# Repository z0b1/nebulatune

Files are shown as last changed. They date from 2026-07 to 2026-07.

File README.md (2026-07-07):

# NebulaTune

NebulaTune is a HF reciever utilizng a Direct Conversion Single Balanced Diode Product Detector along with an RP2350 to display and choose frequency and recieve with an digital encoder!

## Preview

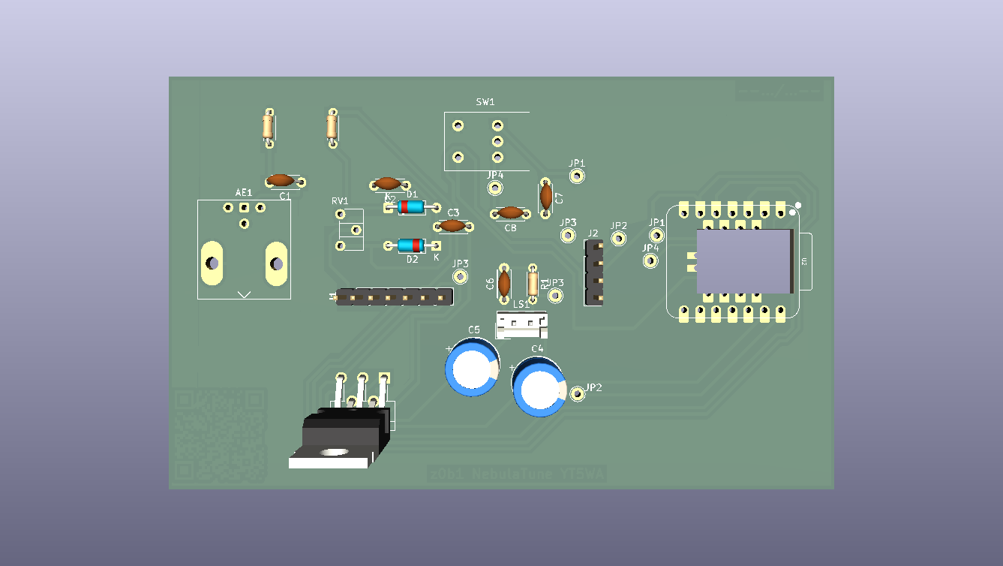
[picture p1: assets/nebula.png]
PCB preview

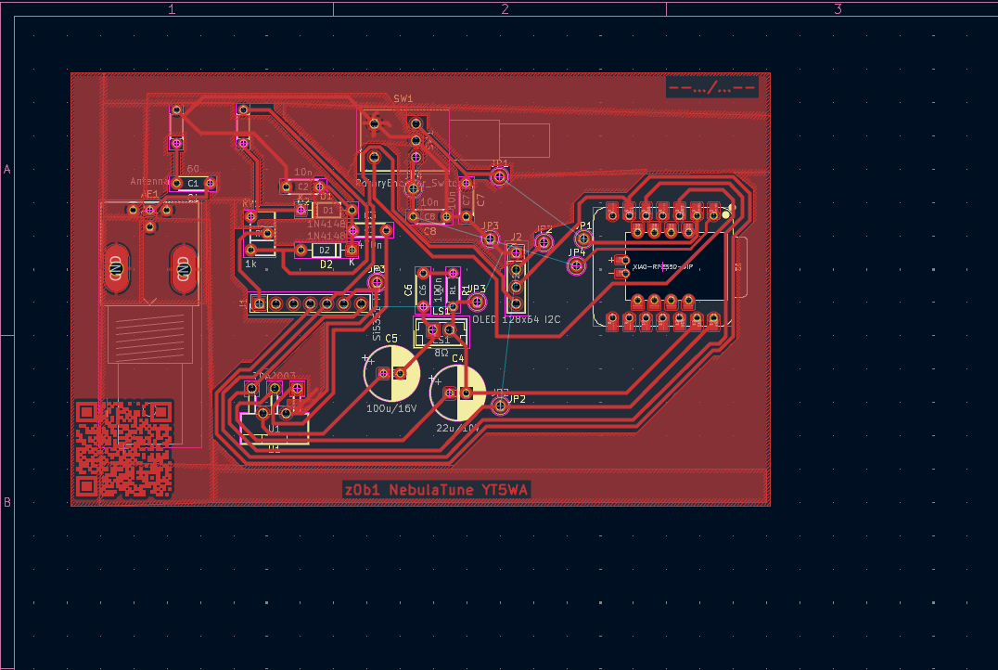
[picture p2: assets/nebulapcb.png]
Routing preview

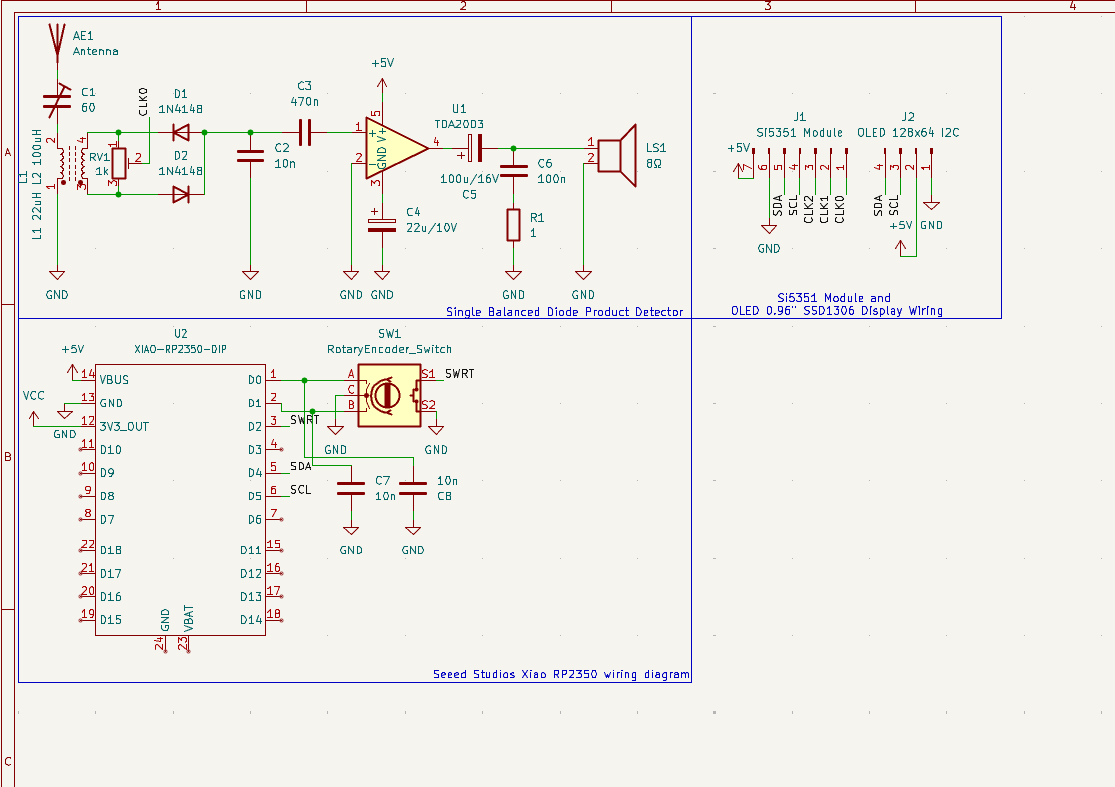
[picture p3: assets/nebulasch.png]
Schematic preview

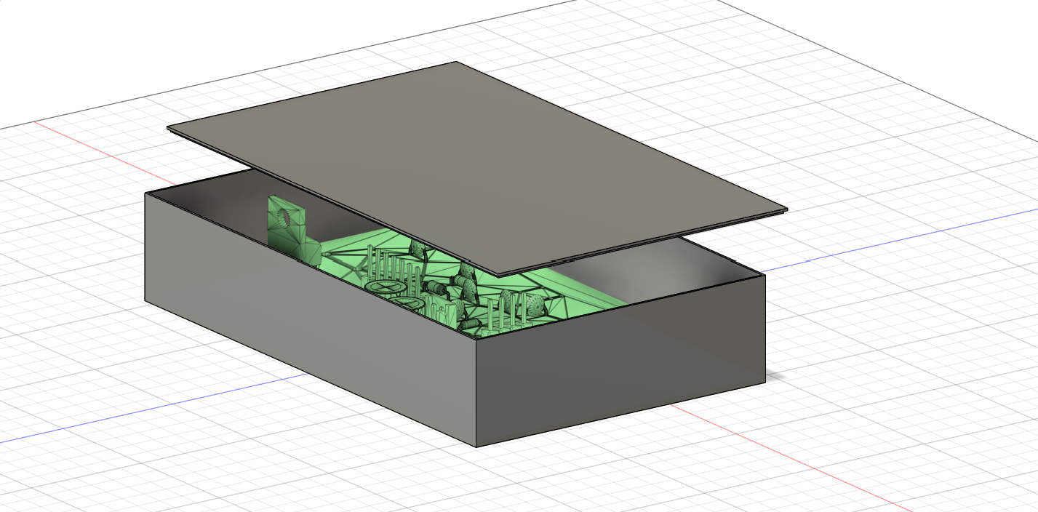
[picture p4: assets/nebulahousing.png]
Housing preview

---
# Lapse link
[View Timelapses](https://lapse.hackclub.com/timelapse/dcauUObcYn6o/)
---
# Demo

##  - link to the PCB on KiCanvas
## SCH in KiCanvas (https://kicanvas.org/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) - link to the SCH on KiCanvas

# Features

- Adjustable VFO with a rotary encoder;
- Frequency display;
- Direct Conversion Single Balanced Diode Product Detector;
- Speaker or headphones output;
- Wide range of frequencies(3-30MHz);
- Local oscillator high stability crystal Si5351 by SiliconLabs;
- SDR and waterfall display soon&trade;.

# DIY How to

1. Analyze the schematic and PCB design and determine if these fit your needs;

2. Gather all of the needed parts from the BOM;

3. A housing is wished for but not needed especially if you plan on tweaking my design;

4. Print the PCB(Only the `F.Cu` and that is in reverse) or order it from JLCPCB(not sponsored);

5. Install the MicroPico extension if using VS Code or just use Thonny;

6. More to come later...

# How it works
 
## General overview

This direct conversion single balanced diode product detector setup is pretty common, it utilizes the Si5351 as the local VFO. That way we eliminate the need for a frequency counter, because the frequency can be set and read with the RP2350!

## Tech details
Now lets get to the core, this direct conversion single balanced diode product detector is similar to Polyakov's mixer which is a small and easy to setup/begginer friendly HF reciever. I took inspo for the 7MHz band design, but with some tweaking the reciever should work on the whole HF band. I choose to make a reciever becuase you don't need a license to listen, and hope to bring more people into Ham Radio. The reason I used the RP2350 is because I hope to make a waterfall and split this into I and Q signals, so I can do ADC on the RP2350 and hopefully make an HF SDR Transciever.

## Explanation

Now, I hope that the reader know what HF and SDR mean, but just in case if someone doesn't know, I will explain the meaning of HF and SDR to you, also some other technical terms I used in this README.
HF just means High Frequency and that is the defined range of frequencies **in this case (3MHz to 30MHz)**. There are also other ranges like VHF, UHF, EHF, SHF and so on!
SDR means Software Defined Radio, that is if your microcontroller/PC analyze the input values of your ADC(Analog to Digital Converter) and visualise it and control the Radio via the Software.

## I'd like to add

I'd like to add although I'm in this hobby for 8 years already, and despite me being a hardware fanatic this is only my second RF project so please contribute and tell me if I have made any mistakes! Also I'm currentley looking for sponsors for my YSWS called **Propagation**!
### Propagation

Propagation is a Hack Club YSWS in production, the idea behind this is that many people have never heard of or tried the magics of RF, our goal is to get people to make projects relating RF, learn about RF and maybe get into the hobby. What separates us from other Radio related YSWS's is that we do not require a license, would be incredible if you have one but our main goal is to expand the use of RF in every sphere of life!
# Credits
Big shoutout to my father, without him, having patience and will to work is getting hard as I easily get annoyed but he gets me to enjoy this, also he's the main finder of other open source projects which I later work on and modify
---
### The idea for using the Si5351
---
[Link to github repository of the inspo for the Si5351.](https://github.com/TeknoTrek/Si5351-Clock-Generator-for-Arduino-Projects)
---
### The idea for the Direct Conversion Single Balanced Diode Product Detector
---
[Link to the Direct Conversion Single Balanced Diode Product Detector.](https://ra1ohx.ru/publ/skhemy_radioljubitelju/priemniki/prostoj_priemnik_prjamogo_preobrazovanija_na_diapazon_7_mgc/13-1-0-153)
---
> Translate the site to english, its in russian.
# Bill Of Materials
---
|Reference|Part|Qty|Price|Total|Description|
|:---|:---:|:---|:---:|:---:|:---:|
|AE1|Antenna|1|3.66E|3.66E|BNC CONNECTOR|
|C1|Capacitor|1|0.3E|0.3E|60|
|C2,C7,C8|Capacitor|3|0.1E|0.3E|10n|
|C3|Capacitor|1|0.15|0.15|470n|
|C4|CP|1|0.2|0.2|22u/10V|
|C5|CP|1|X|X|100u/16V|
|C6|Capacitor|1|X|X|100n|
|D1,D2|Diode|2|X|X|1N4148|
|J1|VFO|1|6.5|6.5|Si5351|
|J2|Display|1|6.8|6.8|OLED 128x64 I2C|
|L1|Inductor/Choke Coupled|1|0.2|0.2|L1 22uH L2 100uH|
|LS1|Speaker|1|2.8|2.8|8Ohm|
|R1|Resistor|1|x|x|1|
|RV1|Trimmer|1|0.2|0.2|1k|
|SW1|Rotary encoder swithch|1|1|1|/|
|U1|TDA2003|1|1.5|1.5|Audio amp|
|U2|XIAO RP2350 DIP|1|9|9|Main MCU|
> Total 32.61 Euros or 37.33 USD, price might vary for shipping and availabilty reasons.

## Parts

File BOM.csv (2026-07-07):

Reference | Qty | Value | DNP | Exclude from BOM | Exclude from Board | Footprint | Datasheet
AE1 | 1 | Antenna |  |  |  | Connector_Coaxial:BNC_Amphenol_031-6575_Horizontal
C1 | 1 | 60 |  |  |  | Capacitor_THT:C_Disc_D4.3mm_W1.9mm_P5.00mm
C2,C7,C8 | 3 | 10n |  |  |  | Capacitor_THT:C_Disc_D4.3mm_W1.9mm_P5.00mm
C3 | 1 | 470n |  |  |  | Capacitor_THT:C_Disc_D4.3mm_W1.9mm_P5.00mm
C4 | 1 | 22u/10V |  |  |  | Capacitor_THT:CP_Radial_D8.0mm_P2.50mm
C5 | 1 | 100u/16V |  |  |  | Capacitor_THT:CP_Radial_D8.0mm_P2.50mm
C6 | 1 | 100n |  |  |  | Capacitor_THT:C_Disc_D4.3mm_W1.9mm_P5.00mm
D1,D2 | 2 | 1N4148 |  |  |  | Diode_THT:D_DO-35_SOD27_P7.62mm_Horizontal | https://assets.nexperia.com/documents/data-sheet/1N4148_1N4448.pdf
J1 | 1 | Si5351 Module |  |  |  | Connector_PinHeader_2.54mm:PinHeader_1x07_P2.54mm_Vertical
J2 | 1 | OLED 128x64 I2C |  |  |  | Connector_PinHeader_2.54mm:PinHeader_1x04_P2.54mm_Vertical
L1 | 1 | L1 22uH L2 100uH |  |  |  | Inductor_THT:L_CommonMode_Wuerth_WE-CMB-L
LS1 | 1 | 8Ω |  |  |  | Connector_JST:JST_EH_B2B-EH-A_1x02_P2.50mm_Vertical
R1 | 1 | 1 |  |  |  | Resistor_THT:R_Axial_DIN0204_L3.6mm_D1.6mm_P5.08mm_Horizontal
RV1 | 1 | 1k |  |  |  | Potentiometer_THT:Potentiometer_ACP_CA6-H2,5_Horizontal
SW1 | 1 | RotaryEncoder_Switch |  |  |  | Rotary_Encoder:RotaryEncoder_Bourns_Horizontal_PEC09-2xxxF-Sxxxx
U1 | 1 | TDA2003 |  |  |  | Package_TO_SOT_THT:TO-220-5_P3.4x3.7mm_StaggerOdd_Lead3.8mm_Vertical | http://www.st.com/resource/en/datasheet/cd00000123.pdf
U2 | 1 | XIAO-RP2350-DIP |  |  |  | Seeed Studio XIAO Series Library:XIAO-RP2350-DIP

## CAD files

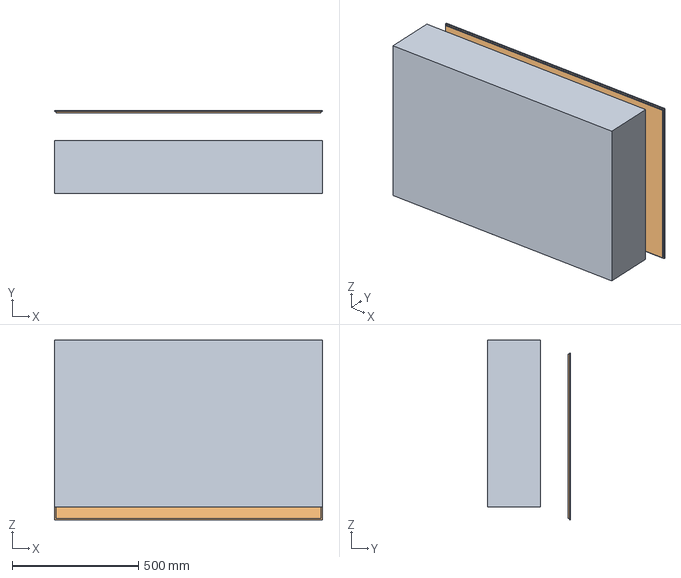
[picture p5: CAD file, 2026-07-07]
CAD/nebulatune_case.step
1060.0 x 330.0 x 710.0 mm

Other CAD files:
CAD/nebulatune_case.stl

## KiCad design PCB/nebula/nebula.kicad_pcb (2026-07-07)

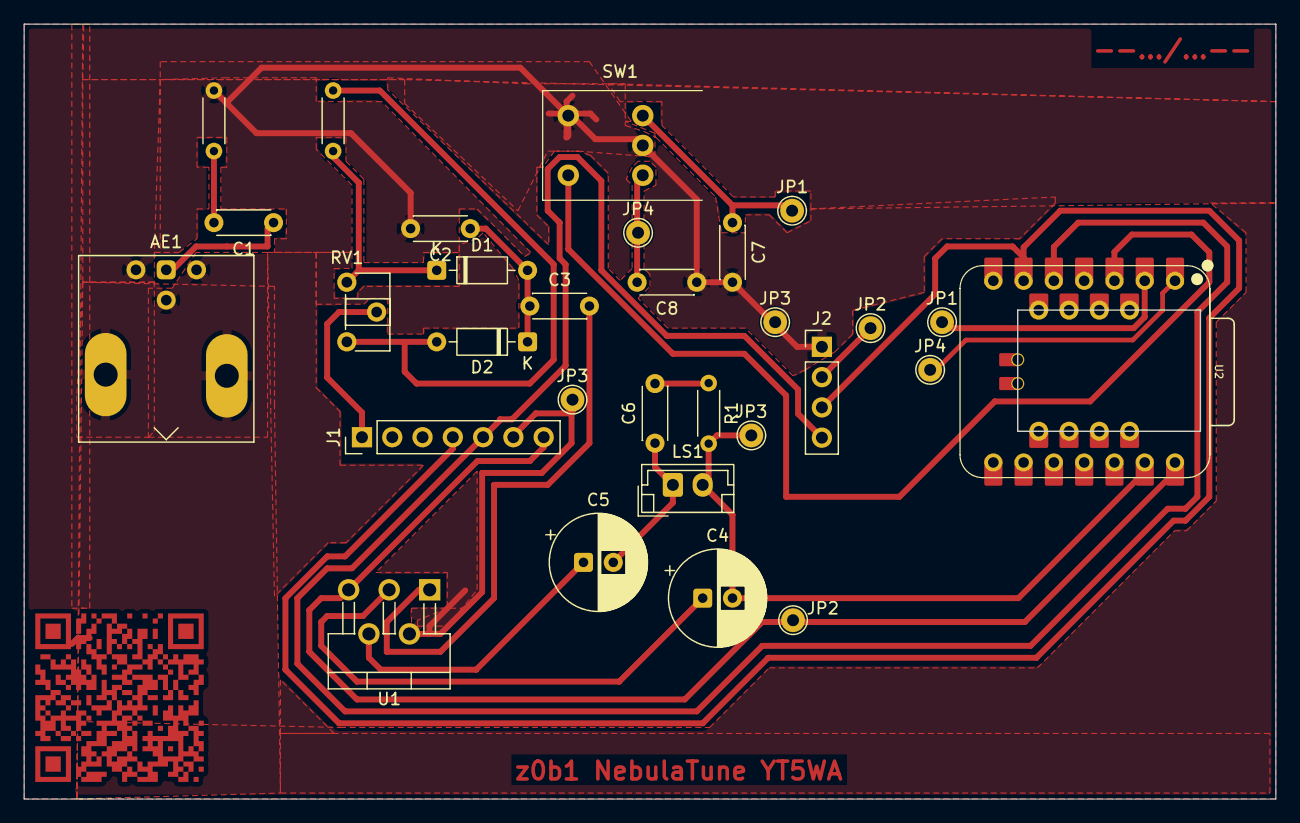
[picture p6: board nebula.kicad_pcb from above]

Board: 2 copper layers, 105.0 x 65.0 mm, 28 parts (0 on the bottom side), 17 nets.

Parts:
AE1: Antenna; BNC_Amphenol_031-6575_Horizontal
C1: 60; C_Disc_D4.3mm_W1.9mm_P5.00mm
C2, C7, C8: 10n; C_Disc_D4.3mm_W1.9mm_P5.00mm
C3: 470n; C_Disc_D4.3mm_W1.9mm_P5.00mm
C4: 22u/10V; CP_Radial_D8.0mm_P2.50mm
C5: 100u/16V; CP_Radial_D8.0mm_P2.50mm
C6: 100n; C_Disc_D4.3mm_W1.9mm_P5.00mm
D1, D2: 1N4148; D_DO-35_SOD27_P7.62mm_Horizontal
J1: Si5351 Module; PinHeader_1x07_P2.54mm_Vertical
J2: OLED 128x64 I2C; PinHeader_1x04_P2.54mm_Vertical
JP1, JP1#2, JP2, JP2#2, JP3, JP3#2, JP3#3, JP4, JP4#2: TestPoint_THTPad_D2.0mm_Drill1.0mm
LS1: 8Ω; JST_EH_B2B-EH-A_1x02_P2.50mm_Vertical
R1: 1; R_Axial_DIN0204_L3.6mm_D1.6mm_P5.08mm_Horizontal
RV1: 1k; Potentiometer_ACP_CA6-H2,5_Horizontal
SW1: RotaryEncoder_Switch; RotaryEncoder_Bourns_Horizontal_PEC09-2xxxF-Sxxxx
U1: TDA2003; TO-220-5_P3.4x3.7mm_StaggerOdd_Lead3.8mm_Vertical
U2: XIAO-RP2350-DIP

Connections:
+5V: J1.7, J2.2, JP2.1, JP2#2.1, U1.5 (V+), U2.14 (VBUS)
/CLK0: J1.1, RV1.2
/SCL: J1.4, J2.3, U2.6 (D5)
/SDA: J1.5, J2.4, U2.5 (D4)
/SWRT: SW1.S1, U2.3 (D2)
GND: AE1.2, AE1.3, AE1.4, C2.2, C4.2, C7.2, C8.1, J1.6, J2.1, JP3.1, JP3#2.1, JP3#3.1, LS1.2, R1.2, SW1.C, SW1.S2, U1.2 (-), U2.13 (GND)
unnamed: AE1.1 (A_1), C1.1
unnamed: C5.1, U1.4
unnamed: C5.2, C6.1, LS1.1
unnamed: C6.2, R1.1
unnamed: C2.1, C3.1, D1.2 (A), D2.1 (K)
unnamed: D1.1 (K), RV1.1
unnamed: D2.2 (A), RV1.3
unnamed: C3.2, U1.1 (+)
unnamed: C4.1, U1.3 (GND)
unnamed: C8.2, JP4.1, JP4#2.1, SW1.A, U2.1 (D0)
unnamed: C7.1, JP1.1, JP1#2.1, SW1.B, U2.2 (D1)

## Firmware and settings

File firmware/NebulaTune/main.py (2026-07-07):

import machine
import utime
from si5351 import SI5351
from ssd1306 import SSD1306_I2C

i2c = machine.I2C(0, sda=machine.Pin(4), scl=machine.Pin(5))

try:
    oled = SSD1306_I2C(128, 64, i2c)
    print("OLED detected successfully")
except Exception as e:
    print("Error initalizing", e)
    oled = None

try:
    crystal_freq = 25000000
    clock_gen = SI5351(i2c, crystal_freq)
    print("SI5351 detected successfully")
except Exception as e:
    print("Error initializing SI5351", e)
    clock_gen = None

frequency = 7000000 # Starting frequency 7.000MHz
steps = [1000, 10000, 100000] #step sizes for freq adjustment 1kHz 10kHz 100kHz 
step_index = 0
current_step = steps[step_index]

clk_pin = machine.Pin(0, machine.Pin.IN, machine.Pin.PULL_UP) # Pin 0 is used for frequency adjustment
dt_pin = machine.Pin(1, machine.Pin.IN, machine.Pin.PULL_UP) # Pin 1 is used for frequency adjustment
switch_pin = machine.Pin(2, machine.Pin.IN, machine.Pin.PULL_UP) # Pin 2 is used for step size adjustment

last_clk_state = clk_pin.value()
last_switch_time = 0

def update_system(freq):

    if clock_gen:
        try:
            clock_gen.set_freq(0, freq)
        except Exception as e:
            print("Error setting frequency", e)
    if oled:
        oled.fill(0)

        oled.text("NebulaTune", 4,2,1)
        oled.text("----------------", 0, 12, 1)
        freq_mhz = freq / 1000000
        oled.text(f"FREQ: {freq_mhz:.4f} MHz", 0, 28, 1)
        step_khz = current_step / 1000
        oled.text(f"STEP: {step_khz:g} kHz", 0, 48, 1)
        oled.show()
update_system(frequency)

while True:
    current_clk_state = clk_pin.value()
    if current_clk_state != last_clk_state:

        if dt_pin.value() != current_clk_state:
            frequency += current_step
        else:
            frequency -= current_step
        
        if frequency < 0:
            frequency = 0

        update_system(frequency)
        utime.sleep_ms(2)  # Debounce delay

    last_clk_state = current_clk_state

    if switch_pin.value() == 0:
        current_time = utime.ticks_ms()
        if current_time - last_switch_time > 200:  # Debounce delay
            step_index = (step_index + 1) % len(steps)
            current_step = steps[step_index]
            update_system(frequency)
            last_switch_time = current_time
    utime.sleep_ms(3)  # Main loop delay

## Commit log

2026-07-07 Fixed unconnected zones
    [nebula.kicad_pcb]
2026-07-07 Added the BOM
    [BOM.csv]
2026-07-07 Finished prices for BOM
